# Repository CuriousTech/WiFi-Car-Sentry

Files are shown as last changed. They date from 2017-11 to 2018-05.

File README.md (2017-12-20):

# WiFi Car Sentry
Low power car monitor and control system  
  
Revision 2  
  
Using the ESP07, it connects with the home WiFi to report information on timer using DeepSleep.  Remember to remove the red LED on the ESP to reduce current.  This new revision uses a switching regulator for the lowest current possible.  It uses about 25mA on, and 39µA in sleep at 12.5V.  
  
I/O peripherals:  
  OLED (optional for temporary display)  
  DHT22 for temperature and Rh  
  0-17V analog voltage reading  
  2x 1-40V digital input (for sensing if something is on)  
  3x sink inputs (alarm or sensor)  
  3 sink outputs for controlling relays, etc (the bom has 7.6A MOSFETs)  
  Plus extra O/I for GPS or other sensors. The outputs can be used to switch them off for more power saving.  
  
esp07carsentry
esp07pmwin
esp07cs_wp

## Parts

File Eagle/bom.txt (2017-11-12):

ESP-07
OLED        0.96" I2C (GND on pin 1)
DHT-22
3V3 VR      LMR16006YQ3DDCRQ1
D5  SOT-223    NSVR0320MW2T1G
L1  0805 6.8uF IFSC0806AZER6R8M01
R1-R5,R7    10K 0805 (or 0603)
R6,R9,R14   1K
R8          2.2K
R10         100K
R11         6.34K
R12,R13      4.7K
C1  0805 2.2uF
C4  0805 10uF  08056C106KAT2A
C3,C6,C7,C8,C9,C11 0.1uF (0805 or 0603)
Q1,Q3,Q6    SOT-23 P-Channel FET <3V gate threshold (SI2369DS-T1-GE3)
Q2          SOT-23 N-Channel FET (PMV20ENR)
Q4,Q5       SOT-23 General purpose NPN

FLASH       4x2mm buttton
RX/TX/GND   3-pin 0.1" header (hold in place, then use OTA)

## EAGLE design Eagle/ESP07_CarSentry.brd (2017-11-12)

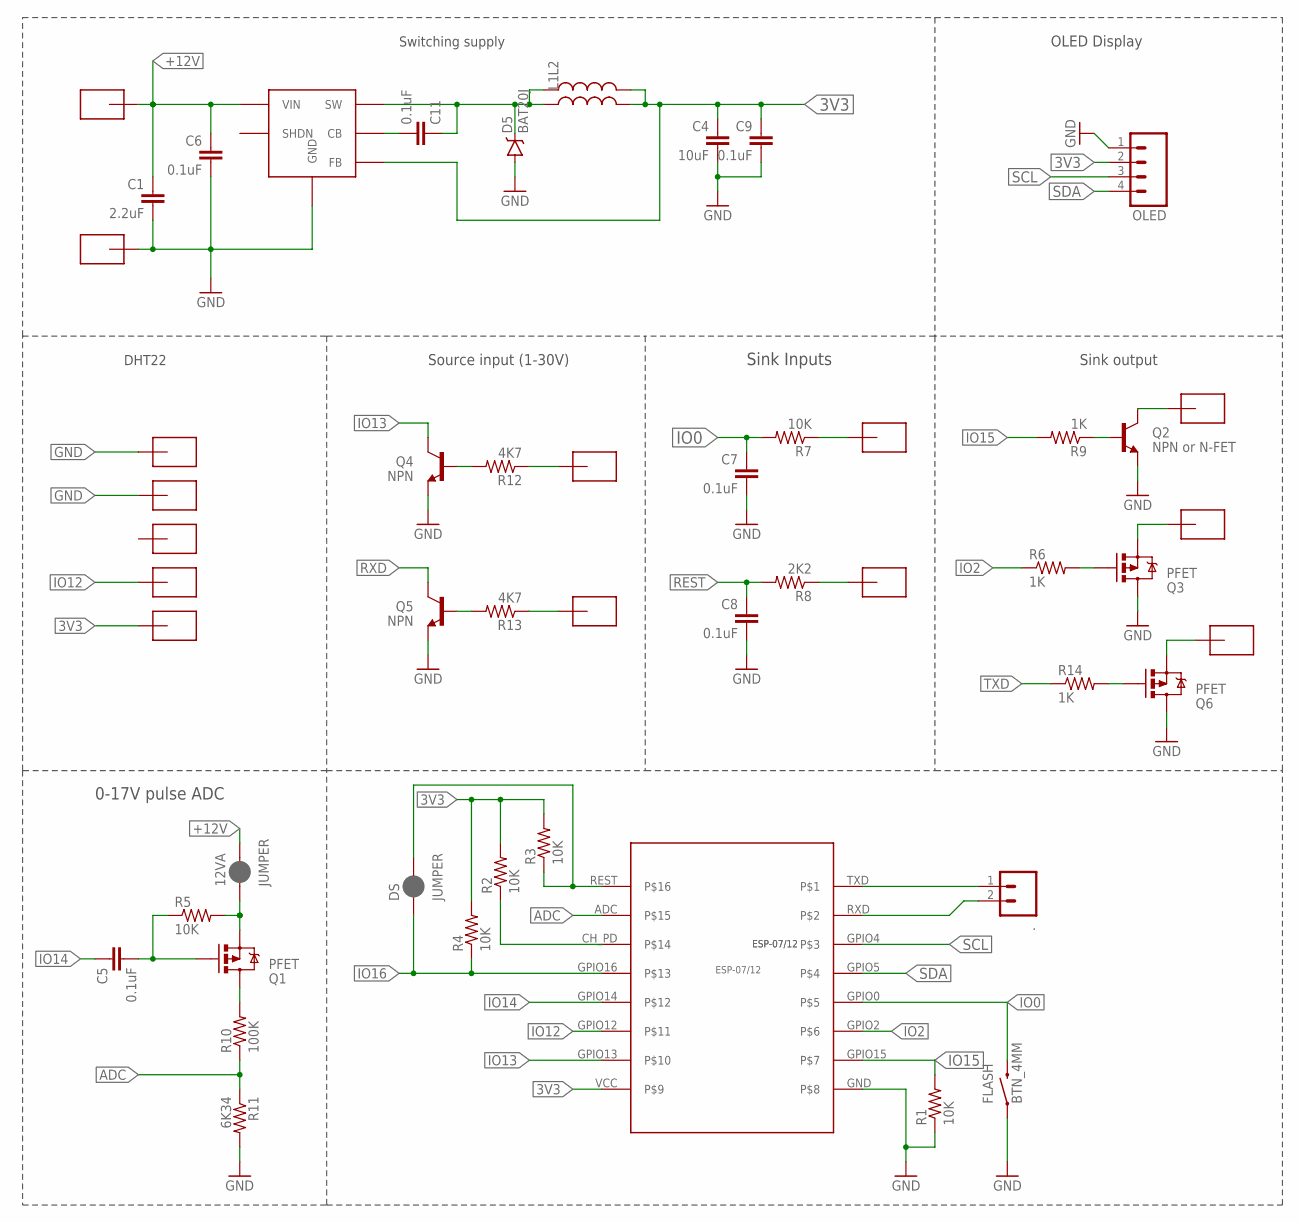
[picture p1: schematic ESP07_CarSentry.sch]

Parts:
12VA: JUMPER; PAD-JUMPER-2-NC_BY_PASTE_YES_SILK
.: M02PTH; 1X02
C1: 2.2uF; 0805-CAP
C4: 10uF; 0805-CAP
C5, C6, C7, C8, C9, C11: 0.1uF; 0805-CAP
D5: BAT20J; SOD-323
DS: JUMPER; PAD-JUMPER-2-NC_BY_PASTE_YES_SILK
FLASH: BTN_4MM
L1, L2: INDUCTOR0805; 0805
OLED: M04LOCK; 1X04_LOCK
Q1, Q3, Q6: PFET; SOT23-3
Q2: NPN or N-FET; SOT23-3
Q4, Q5: NPN; SOT23-3
R1, R2, R3, R4, R5, R7: 10K; 0805
R6, R9, R14: 1K; 0805
R8: 2K2; 0805
R10: 100K; 0805
R11: 6K34; 0805
R12, R13: 4K7; 0805
U$1: ESP-07/12
U$2, U$3, U$4, U$5, U$6, U$7, U$8, U$9, U$10, U$11, U$12, U$13, U$14, U$16: SMD-PAD1
VREG1: LMR16006YQ3DDCRQ1; SOT-23-6

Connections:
3V3: C4.1, C9.1, L1.2, L2.2, OLED.2, R2.2, R3.2, R4.2, U$1.VCC, U$4.>NAME, VREG1.3 (FB)
+12V: 12VA.2, C1.1, C6.1, U$16.>NAME, VREG1.5 (VIN)
ADC: R10.1, R11.1, U$1.ADC
ADCHI: 12VA.1, Q1.2 (S), R5.2
GND: C1.2, C4.2, C6.2, C7.2, C8.2, C9.2, D5.A, FLASH.1, OLED.1, Q2.2 (E), Q3.3 (D), Q4.2 (E), Q5.2 (E), Q6.3 (D), R1.1, R11.2, U$1.GND, U$6.>NAME, U$8.>NAME, U$11.>NAME, VREG1.2 (GND)
IO0: C7.1, FLASH.2, R7.2, U$1.GPIO0
IO2: R6.1, U$1.GPIO2
IO12: U$1.GPIO12, U$5.>NAME
IO13: Q4.3 (C), U$1.GPIO13
IO14: C5.1, U$1.GPIO14
IO15: R1.2, R9.2, U$1.GPIO15
IO16: DS.1, R4.1, U$1.GPIO16
unnamed: Q1.3 (D), R10.2
unnamed: Q3.1 (G), R6.2
unnamed: C5.2, Q1.1 (G), R5.1
unnamed: Q3.2 (S), U$9.>NAME
unnamed: R7.1, U$14.>NAME
unnamed: Q2.1 (B), R9.1
unnamed: Q2.3 (C), U$3.>NAME
unnamed: R8.1, U$12.>NAME
unnamed: Q4.1 (B), R12.2
unnamed: R12.1, U$2.>NAME
unnamed: R2.1, U$1.CH_PD
unnamed: Q5.1 (B), R13.2
unnamed: C11.1, D5.C, L1.1, L2.1, VREG1.6 (SW)
unnamed: C11.2, VREG1.1 (CB)
unnamed: R13.1, U$10.>NAME
unnamed: Q6.2 (S), U$13.>NAME
unnamed: Q6.1 (G), R14.2
REST: C8.1, DS.2, R3.1, R8.2, U$1.REST
RXD: ..2, Q5.3 (C), U$1.RXD
SCL: OLED.3, U$1.GPIO4
SDA: OLED.4, U$1.GPIO5
TXD: ..1, R14.1, U$1.TXD

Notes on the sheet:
0-17V pulse ADC
Sink Inputs
DHT22
Sink output
Source input (1-30V)
OLED Display
Switching supply

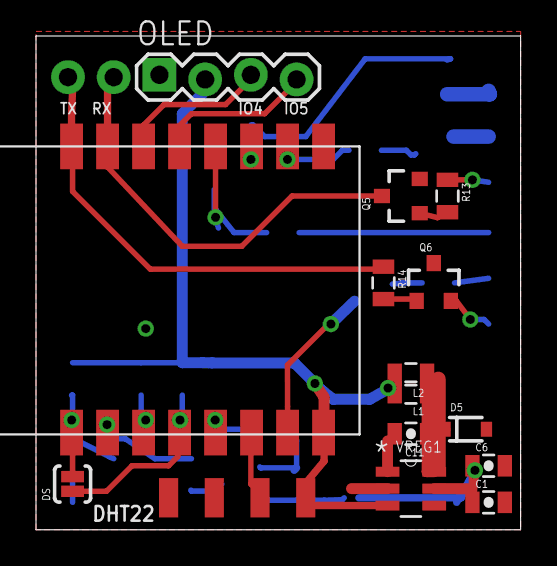
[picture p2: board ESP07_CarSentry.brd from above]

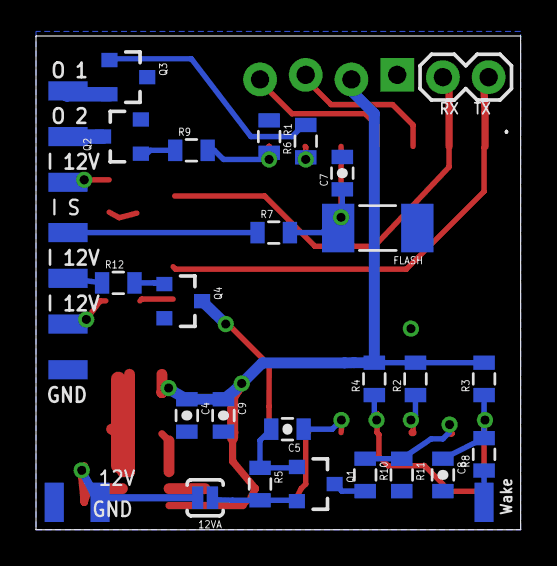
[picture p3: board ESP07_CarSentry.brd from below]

Board: 2 copper layers, 26.9 x 27.4 mm, 52 parts (34 on the bottom side), 34 nets.

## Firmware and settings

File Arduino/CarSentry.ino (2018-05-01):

/**The MIT License (MIT)

Copyright (c) 2017 by Greg Cunningham, CuriousTech

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
THE SOFTWARE IS PROVIDED "AS IS", WITHOUT WARRANTY OF ANY KIND, EXPRESS OR
IMPLIED, INCLUDING BUT NOT LIMITED TO THE WARRANTIES OF MERCHANTABILITY,
FITNESS FOR A PARTICULAR PURPOSE AND NONINFRINGEMENT. IN NO EVENT SHALL THE
AUTHORS OR COPYRIGHT HOLDERS BE LIABLE FOR ANY CLAIM, DAMAGES OR OTHER
LIABILITY, WHETHER IN AN ACTION OF CONTRACT, TORT OR OTHERWISE, ARISING FROM,
OUT OF OR IN CONNECTION WITH THE SOFTWARE OR THE USE OR OTHER DEALINGS IN THE
SOFTWARE.
*/

//uncomment to enable Arduino IDE Over The Air update code
#define OTA_ENABLE

//#define DEBUG
//#define USE_SPIFFS

#include <Wire.h>
#include <ssd1306_i2c.h> // https://github.com/CuriousTech/WiFi_Doorbell/tree/master/Libraries/ssd1306_i2c
#include <EEPROM.h>
#include <ESP8266mDNS.h>
#include "WiFiManager.h"
#include <ESPAsyncWebServer.h> // https://github.com/me-no-dev/ESPAsyncWebServer
#ifdef USE_SPIFFS
#include <FS.h>
#include <SPIFFSEditor.h>
#else
#include "pages.h"
#endif
#ifdef OTA_ENABLE
#include <FS.h>
#include <ArduinoOTA.h>
#endif
#include <OneWire.h>
#include <TimeLib.h> // http://www.pjrc.com/teensy/td_libs_Time.html
#include <UdpTime.h>
#include <DHT.h>  // http://www.github.com/markruys/arduino-DHT
#include "eeMem.h"
#include <JsonClient.h> // https://github.com/CuriousTech/ESP8266-HVAC/tree/master/Libraries/JsonParse

const char controlPassword[] = "password";    // device password for modifying any settings
const int serverPort = 81;                    // HTTP port

#define IN1       0  // Sink input 1 (Direct sink 5V tolerant)
#define OUT3      1  // TX Sink output 3 MOSFET (high to sink)
#define OUT1      2  // Sink output 1 MOSFET (low to sink) (Note: Rev 1 has P-channel here)
#define ESP_LED   2  // Blue LED on ESP07 (on low)
#define IN2       3  // RX 1~40V input (sink)
#define SDA       4  // OLED
#define SCL       5  // OLED
#define DHT22IO  12  // The DHT22
#define IN12V    13  // 1~30V input (sink) use PULLUP
#define VOLTFET  14  // voltage reading MOSFET
#define OUT2     15  // Sink output 2 MOSFET (high to sink)
#define SLEEP    16  // Wake pin

uint32_t lastIP;

SSD1306 display(0x3C, SDA, SCL); // Initialize the oled display for address 0x3C, SDA=4, SCL=5 (is the OLED mislabelled?)
int displayOnTimer;

eeMem eemem;
DHT dht;
UdpTime utime;

WiFiManager wifi;  // AP page:  192.168.4.1
AsyncWebServer server( serverPort );
AsyncEventSource events("/events"); // event source (Server-Sent events)
AsyncWebSocket ws("/ws"); // access at ws://[esp ip]/ws

uint16_t rh;
int16_t carTemp;
uint16_t volts;
uint16_t ssCnt = 10;
const char hostName[] = "CarSentry";
bool bKeyGood;
uint32_t sleepDelay = 10; // default value for WebSocket close -> sleepTimer
uint32_t sleepTimer = 60; // seconds delay after startup to enter sleep (Note: even if no AP found)
int8_t openCnt;
uint8_t nPulse;
uint8_t pulseCh;
IPAddress WSIP;

void jsonCallback(int16_t iEvent, uint16_t iName, int iValue, char *psValue);
JsonClient jsonParse(jsonCallback);
JsonClient jsonPush(jsonCallback);
void locCallback(int16_t iEvent, uint16_t iName, int iValue, char *psValue);
JsonClient locator(locCallback);

const char days[7][4] = {"Sun","Mon","Tue","Wed","Thr","Fri","Sat"};
const char months[12][4] = {"Jan","Feb","Mar","Apr","May","Jun","Jul","Aug","Sep","Oct","Nov","Dec"};

String dataJson()
{
  String s = "{";
  s += "\"t\": ";  s += now() - ((ee.tz + utime.getDST()) * 3600);
  s += ", \"ct\": ";  s += sDec(carTemp);
  s += ", \"rh\": ";   s += sDec(rh);
  s += ", \"v\": ";   s += (float)volts / 100;
  s += ", \"in1\": ";   s += digitalRead(IN1) ? 0:1;
  s += ", \"in2\": ";   s += digitalRead(IN2) ? 0:1;
  s += ", \"in12v\": ";   s += digitalRead(IN12V) ? 0:1;
  s += ", \"lat\": \"";   s += ee.szLat;
  s += "\", \"lon\": \"";   s += ee.szLon;
  s += "\"}";
  return s;
}

String setJson() // settings
{
  String s = "{";
  s += "\"o\":";    s += ee.bEnableOLED;
  s += ",\"tz\":";  s += ee.tz;
  s += ", \"gt\": ";   s += ee.get_time;
  s += ", \"gl\": ";   s += ee.get_loc;
  s += ",\"o1\":";  s += digitalRead(OUT1) ? 0:1;
  s += ",\"o2\":";  s += digitalRead(OUT2) ? 1:0;
  s += ",\"o3\":";  s += digitalRead(OUT3) ? 1:0;
  s += ",\"to\": "; s += ee.time_off;
  s += ", \"ro\": ";   s += ee.roaming;
  s += ",\"d\": \""; s += ee.szDomain;
  s += "\"}";
  return s;
}

void parseParams(AsyncWebServerRequest *request)
{
  static char temp[256];
  char password[64];
  int val;

 if(request->params() == 0)
    return;

  // get password first
  for ( uint8_t i = 0; i < request->params(); i++ ) {
    AsyncWebParameter* p = request->getParam(i);
    p->value().toCharArray(temp, 100);
    String s = wifi.urldecode(temp);
    switch( p->name().charAt(0)  )
    {
      case 'k': // key
        s.toCharArray(password, sizeof(password));
        break;
    }
  }

  uint32_t ip = request->client()->remoteIP();

  if(strcmp(controlPassword, password))
  {
    lastIP = ip;
    return;
  }

  lastIP = ip;

  for ( uint8_t i = 0; i < request->params(); i++ ) {
    AsyncWebParameter* p = request->getParam(i);
    p->value().toCharArray(temp, 100);
    String s = wifi.urldecode(temp);

    val = s.toInt();

    switch( p->name().charAt(0)  )
    {
      case 'h': // host IP / port  (call from host with ?h=80)
        ee.hostIP = ip;
        ee.hostPort = val ? val:80;
        break;
      case 't': // time off
        ee.time_off = val;
        break;
      case 's': // AP SSID
        s.toCharArray(ee.szSSID, sizeof(ee.szSSID));
        break;
      case 'p': // AP password
        wifi.setPass(s.c_str());
        break;
    }
  }
}

String sDec(int t) // just 123 to 12.3 string
{
  String s = String( t / 10 ) + ".";
  s += t % 10;
  return s;
}

// Time in hh:mm[:ss][AM/PM]
String timeFmt(bool do_sec, bool do_M)
{
  String r = "";
  if(hourFormat12() < 10) r = " ";
  r += hourFormat12();
  r += ":";
  if(minute() < 10) r += "0";
  r += minute();
  if(do_sec)
  {
    r += ":";
    if(second() < 10) r += "0";
    r += second();
    r += " ";
  }
  if(do_M)
  {
      r += isPM() ? "PM":"AM";
  }
  return r;
}

void handleS(AsyncWebServerRequest *request) { // standard params, but no page
  parseParams(request);

  String page = "{\"ip\": \"";
  page += WiFi.localIP().toString();
  page += ":";
  page += serverPort;
  page += "\"}";
  request->send ( 200, "text/json", page );
}

void onEvents(AsyncEventSourceClient *client)
{
  events.send(dataJson().c_str(), "state");
}

void sendState()
{
  String s = dataJson();
  events.send(s.c_str(), "state");
  ws.textAll(String("state;") + s);
  ssCnt = 58;
}

const char *jsonListCmd[] = { "cmd",
  "key",
  "oled",
  "TZ", // location
  "TO", // time_off
  "sleep",
  "O1", // OUT1
  "O2",
  "O3",
  "PLS", // Pulse OUTn for 1 second
  "GT", // get time
  "GL", // get location
  "HI", // host IP/port
  "SD", // set domain
  "RO", // roaming
  NULL
};
      
void jsonCallback(int16_t iEvent, uint16_t iName, int iValue, char *psValue)
{
  if(!bKeyGood && iName) return; // only allow for key

  switch(iEvent)
  {
    case 0: // cmd
      switch(iName)
      {
        case 0: // key
          if(!strcmp(psValue, controlPassword)) // first item must be key
            bKeyGood = true;
          break;
        case 1: // OLED
          ee.bEnableOLED = iValue ? true:false;
          break;
        case 2: // TZ
          ee.tz = iValue;
          utime.start();
          break;
        case 3: // TO
          ee.time_off = iValue;
          break;
        case 4: // sleep
          sleepDelay = constrain(iValue, 1, 10000);
          break;
        case 5: // O1=n
          digitalWrite(OUT1, iValue ? LOW:HIGH);
          break;
        case 6: // O2=n
          digitalWrite(OUT2, iValue ? HIGH:LOW);
          break;
        case 7: // O3=n
          digitalWrite(OUT3, iValue ? HIGH:LOW);
          break;
        case 8: // PLS=Ch
          nPulse = 2;
          pulseCh = iValue;
          break;
        case 9: // GT
          ee.get_time = iValue ? true:false;
          break;
        case 10: // GL
          ee.get_loc = iValue ? true:false;
          break;
        case 11: // host IP / port  (call from host with ?h=80)
          ee.hostIP = WSIP;
          ee.hostPort = iValue ? iValue:80;
          break;
        case 12: // global domain
          strncpy(ee.szDomain, psValue, sizeof(ee.szDomain));
          break;
        case 13: // RO
          ee.roaming = iValue ? true:false;
          break;
      }
      break;
  }
}

const char *jsonListLoc[] = { "data",
  "result",
  "lat",
  "lon",
  "time",
  NULL
};
      
void locCallback(int16_t iEvent, uint16_t iName, int iValue, char *psValue)
{
  switch(iEvent)
  {
    case 0: // cmd
      switch(iName)
      {
        case 0: // result
          break;
        case 1: // lat
          strncpy(ee.szLat, psValue, sizeof(ee.szLat) );
          ee.locRoam = wifi.isSecure();
          break;
        case 2: // lon
          strncpy(ee.szLon, psValue, sizeof(ee.szLon) );
          break;
        case 3: // time
          utime.set(iValue, ee.tz);
          break;
      }
      break;
  }
}

void onWsEvent(AsyncWebSocket * server, AsyncWebSocketClient * client, AwsEventType type, void * arg, uint8_t *data, size_t len)
{  //Handle WebSocket event
  String s;

  switch(type)
  {
    case WS_EVT_CONNECT:      //client connected
      s = String("state;") + dataJson().c_str();
      client->text(s);
      s = String("set;") + setJson().c_str();
      client->text(s);
      client->ping();
      WSIP = client->remoteIP();
      openCnt++;
      break;
    case WS_EVT_DISCONNECT:    //client disconnected
      if(openCnt)
        openCnt--;
      if(sleepDelay)
        sleepTimer = sleepDelay;
      break;
    case WS_EVT_ERROR:    //error was received from the other end
      break;
    case WS_EVT_PONG:    //pong message was received (in response to a ping request maybe)
      break;
    case WS_EVT_DATA:  //data packet
      AwsFrameInfo * info = (AwsFrameInfo*)arg;
      if(info->final && info->index == 0 && info->len == len){
        //the whole message is in a single frame and we got all of it's data
        if(info->opcode == WS_TEXT){
          data[len] = 0;

          char *pCmd = strtok((char *)data, ";"); // assume format is "name;{json:x}"
          char *pData = strtok(NULL, "");
          if(pCmd == NULL || pData == NULL) break;
          bKeyGood = false; // for callback (all commands need a key)
          jsonParse.process(pCmd, pData);
        }
      }
      break;
  }
}

volatile bool bIn1Triggered;

void in1ISR()
{
  bIn1Triggered = true;
}

volatile bool bIn12VTriggered;

void in12VISR()
{
  bIn12VTriggered = true;
}

void setup()
{
  pinMode(IN1, INPUT_PULLUP);
  pinMode(IN12V, INPUT_PULLUP);
  pinMode(VOLTFET, OUTPUT);
  digitalWrite(OUT1, HIGH);
  pinMode(OUT1, OUTPUT);
  pinMode(OUT2, OUTPUT);

  // initialize dispaly
  display.init();
  display.flipScreenVertically();

#ifdef DEBUG
  Serial.begin(115200);
  delay(3000);
  Serial.println();
#endif

  WiFi.hostname(hostName);
  if(!wifi.autoConnect(hostName, controlPassword, ee.roaming)) // Tries config AP.  goes to DeepSleep if not found
  {
    if(digitalRead(IN1) == LOW) // hold the flash button down a couple seconds after powerup to clear SSID and password
    {                           // don't use this if IN1 is connected to something
      ee.szSSID[0] = 0;
      ee.szSSIDPassword[0] = 0;
      eemem.update();
#ifdef DEBUG
      Serial.println("SSID cleared");
      delay(1000);
#endif
    }
    uint32_t us = 1000000; // 1 second to restart
    display.displayOff();
    ESP.deepSleep(us, WAKE_RF_DEFAULT);
  }

  if(wifi.isCfg() == false)
  {
#ifdef DEBUG
    Serial.println("");
    Serial.println("WiFi connected");
    Serial.print("IP address: ");
    Serial.println(WiFi.localIP());
#endif
    MDNS.begin ( hostName, WiFi.localIP() );
  }

  MDNS.addService("http", "tcp", serverPort);

#ifdef USE_SPIFFS
  SPIFFS.begin();
  server.addHandler(new SPIFFSEditor("admin", controlPassword));
#endif

  attachInterrupt(IN1, in1ISR, FALLING);
  attachInterrupt(IN12V, in12VISR, CHANGE);

  // attach AsyncEventSource
  events.onConnect(onEvents);
  server.addHandler(&events);
  // attach AsyncWebSocket
  ws.onEvent(onWsEvent);
  server.addHandler(&ws);

  server.on ( "/", HTTP_GET | HTTP_POST, [](AsyncWebServerRequest *request) // Main webpage interface
  {
    parseParams(request);
    if(wifi.isCfg())
      request->send( 200, "text/html", wifi.page() ); // WIFI config page
    else
    {
    #ifdef USE_SPIFFS
      request->send(SPIFFS, "/index.htm");
    #else
      request->send_P(200, "text/html", page1);
    #endif
    }
  });
  server.on ( "/s", HTTP_GET | HTTP_POST, handleS );
  server.on ( "/set", HTTP_GET, [](AsyncWebServerRequest *request){
    request->send( 200, "text/json", setJson() );
  });
  server.on ( "/json", HTTP_GET, [](AsyncWebServerRequest *request){
    request->send( 200, "text/json", dataJson() );
  });

  server.onNotFound([](AsyncWebServerRequest *request){
    request->send(404);
  });
  server.on("/heap", HTTP_GET, [](AsyncWebServerRequest *request){
    request->send(200, "text/plain", String(ESP.getFreeHeap()));
  });

  server.on("/scan", HTTP_GET, [](AsyncWebServerRequest *request){
    String json = "[";
    int n = WiFi.scanComplete();
    if(n == -2){
      WiFi.scanNetworks(true);
    } else if(n){
      for (int i = 0; i < n; ++i){
        if(i) json += ",";
        json += "{";
        json += "\"rssi\":"+String(WiFi.RSSI(i));
        json += ",\"ssid\":\""+WiFi.SSID(i)+"\"";
        json += ",\"bssid\":\""+WiFi.BSSIDstr(i)+"\"";
        json += ",\"channel\":"+String(WiFi.channel(i));
        json += ",\"secure\":"+String(WiFi.encryptionType(i));
        json += ",\"hidden\":"+String(WiFi.isHidden(i)?"true":"false");
        json += "}";
      }
      WiFi.scanDelete();
      if(WiFi.scanComplete() == -2){
        WiFi.scanNetworks(true);
      }
    }
    json += "]";
    request->send(200, "text/json", json);
    json = String();
  });

  server.onFileUpload([](AsyncWebServerRequest *request, String filename, size_t index, uint8_t *data, size_t len, bool final){
  });
  server.onRequestBody([](AsyncWebServerRequest *request, uint8_t *data, size_t len, size_t index, size_t total){
  });

  server.on("/favicon.ico", HTTP_GET, [](AsyncWebServerRequest *request){
    AsyncWebServerResponse *response = request->beginResponse_P(200, "image/x-icon", favicon, sizeof(favicon));
    response->addHeader("Content-Encoding", "gzip");
    request->send(response);
  });
  server.begin();

#ifdef OTA_ENABLE
  ArduinoOTA.begin();
  ArduinoOTA.onStart([]() {
    eemem.update();
  });
#endif

  dht.setup(DHT22IO, DHT::DHT22);
  jsonParse.addList(jsonListCmd);

  if(wifi.isCfg() == false) // connected to the net
  {
    if(ee.get_time)
      utime.start();
    String sUri = String("/car?lon=\"");
    sUri += ee.szLon;
    sUri += "\"&lat=\"";
    sUri += ee.szLat;
    sUri += "\"";
    IPAddress ip(ee.hostIP);
    String url;
    if(wifi.isSecure())
      url = ip.toString();
    else
      url = ee.szDomain;
    jsonPush.begin(url.c_str(), sUri.c_str(), ee.hostPort, false, false, NULL, NULL);
    jsonPush.addList(jsonListCmd);
    if(ee.szLat[0] == 0 || ee.get_loc || !wifi.isSecure() || ee.locRoam) // only needed first time and when roaming, or was roaming last
      updateLocation();
  }

  sleepTimer = 60;
  ssCnt = 10; // reset to 10 seconds
}

void loop()
{
  static uint8_t hour_save, min_save, sec_save;
  static bool bLastOn;

  MDNS.update();
#ifdef OTA_ENABLE
  ArduinoOTA.handle();
#endif

  if(!wifi.isCfg() && ee.get_time)
    utime.check(ee.tz);

  if(bIn1Triggered) // sink triggered
  {
    bIn1Triggered = false;
//    Serial.println("IN1 triggered");
    events.send("IN1 triggered", "alert");
  }

  if(bIn12VTriggered) // 12V in changed
  {
    bIn12VTriggered = false;
//    Serial.print("12V changed to ");
//    Serial.println( digitalRead(IN12V) );
    sendState();
  }

  if(sec_save != second()) // only do stuff once per second
  {
    sec_save = second();

    static uint8_t dht_cnt = 1;
    if(--dht_cnt == 0)
    {
      dht_cnt = 5;
      uint16_t r = (uint16_t)(dht.getHumidity() * 10);
      if(dht.getStatus() == DHT::ERROR_NONE)
      {
        rh = r;
        carTemp = (dht.toFahrenheit(dht.getTemperature()) * 10);
      }//else Serial.println("Temp error");
    }

    if(--ssCnt == 0) // periodic data update
    {
       sendState();
    }

    switch(nPulse)
    {
      case 1:
        switch(pulseCh)
        {
          case 1: digitalWrite(OUT1, HIGH); break;
          case 2: digitalWrite(OUT2, LOW); break;
          case 3: digitalWrite(OUT3, LOW); break;
        }
        nPulse = 0;
        break;
      case 2:
        switch(pulseCh)
        {
          case 1: digitalWrite(OUT1, LOW); break;
          case 2: digitalWrite(OUT2, HIGH); break;
          case 3: digitalWrite(OUT3, HIGH); break;
        }
        nPulse = 1;
        break;
    }

    if(min_save != minute()) // only do stuff once per minute
    {
      min_save = minute();
      if (hour_save != hour()) // update time daily (at 2AM for DST)
      {
        if( (hour_save = hour()) == 2)
        {
          utime.start();
        }
      }
    }
    if(displayOnTimer)
    {
      displayOnTimer --;
    }

    // 100K / 6.34K to 1V : 17V = 1.008V or 1024 (17/1024=1.66)
    digitalWrite(VOLTFET, LOW);
    uint16_t v = analogRead(0);
    volts = (v * 1.582);
    digitalWrite(VOLTFET, HIGH);
//    Serial.print("volts ");
//    Serial.print(v);
//    Serial.print(" ");
//    Serial.println(volts);

    if(sleepTimer && openCnt == 0 && wifi.isCfg() == false) // don't sleep until all ws connections are closed
    {
      if(--sleepTimer == 0)
      {
        if(ee.time_off)
        {
          eemem.update(); // Update EE if anything changed before entering sleep
          delay(100);

//        uint32_t us = ee.time_off * 1000000 * 60;  // minutes to us
          uint32_t us = ee.time_off * 60022000;  // minutes to us adjusted
          display.displayOff();
          ESP.deepSleep(us, WAKE_RF_DEFAULT);
        }
      }
    }
  }
  
  if(wifi.isCfg())
    return;

  // draw the screen here
  display.clear();

  if(ee.bEnableOLED || displayOnTimer) // draw only ON indicator if screen off
  {
    display.setFontScale2x2(false); // the small text

    String s;
  
    s = timeFmt(true, true); // the default scroller
    s += "  ";
    s += days[weekday()-1];
    s += " ";
    s += String(day());
    s += " ";
    s += months[month()-1];
    s += "  ";

    Scroller(s);

    display.drawString( 8, 22, "Temp");
    display.drawPropString(2, 33, String((float)carTemp / 10, 1) + "]" ); // <- that's a degree symbol
    display.drawString(2, 52, String((float)rh / 10, 1) + "%");
    display.drawString( 88, 22, "Volts");
    display.drawPropString(74, 33, String((float)volts / 100, 1) + "v" );
  }
  display.display();
}

// Text scroller optimized for very long lines
void Scroller(String s)
{
  static int16_t ind = 0;
  static char last = 0;
  static int16_t x = 0;

  if(last != s.charAt(0)) // reset if content changed
  {
    x = 0;
    ind = 0;
  }
  last = s.charAt(0);
  int len = s.length(); // get length before overlap added
  s += s.substring(0, 18); // add ~screen width overlap
  int w = display.propCharWidth(s.charAt(ind)); // measure first char
  if(w > 100) w = 10; // bug in function (0 returns 11637)
  String sPart = s.substring(ind, ind + 18);
  display.drawPropString(x, 0, sPart );

  if( --x <= -(w))
  {
    x = 0;
    if(++ind >= len) // reset at last char
      ind = 0;
  }
}

#define min(a,b) ((a)<(b)?(a):(b))

void updateLocation()
{
  int n = min(WiFi.scanNetworks(false,true), 5);
  if (n <= 0) return;

  String multiAPString = "";
  for(int i = 0; i < n; i++)
  {
    if(i > 0)
      multiAPString += ",";
     multiAPString += WiFi.BSSIDstr(i) + "," + WiFi.RSSI(i);
  }
  char multiAPs[multiAPString.length() + 1];
  multiAPString.toCharArray(multiAPs, multiAPString.length());
  multiAPString = "/wifi?v=1.1&search=";
  multiAPString += encodeBase64(multiAPs, multiAPString.length());
  locator.begin("api.mylnikov.org", multiAPString.c_str(), 80, false, false, NULL, NULL);
  locator.addList(jsonListLoc);
}

/*
 * Base64 code by Rene Nyfenegger:
 * http://www.adp-gmbh.ch/cpp/common/base64.html
 */
String base64_chars = "ABCDEFGHIJKLMNOPQRSTUVWXYZabcdefghijklmnopqrstuvwxyz0123456789+/";

String encodeBase64(char* bytes_to_encode, unsigned int in_len)
{
  String ret;
  int i = 0;
  int j = 0;
  unsigned char char_array_3[3];
  unsigned char char_array_4[4];

  while (in_len--) {
    char_array_3[i++] = *(bytes_to_encode++);
    if (i == 3) {
      char_array_4[0] = (char_array_3[0] & 0xfc) >> 2;
      char_array_4[1] = ((char_array_3[0] & 0x03) << 4) + ((char_array_3[1] & 0xf0) >> 4);
      char_array_4[2] = ((char_array_3[1] & 0x0f) << 2) + ((char_array_3[2] & 0xc0) >> 6);
      char_array_4[3] = char_array_3[2] & 0x3f;

      for(i = 0; (i <4) ; i++)
        ret += base64_chars[char_array_4[i]];
      i = 0;
    }
  }

  if (i)
  {
    for(j = i; j < 3; j++)
      char_array_3[j] = '\0';

    char_array_4[0] = (char_array_3[0] & 0xfc) >> 2;
    char_array_4[1] = ((char_array_3[0] & 0x03) << 4) + ((char_array_3[1] & 0xf0) >> 4);
    char_array_4[2] = ((char_array_3[1] & 0x0f) << 2) + ((char_array_3[2] & 0xc0) >> 6);
    char_array_4[3] = char_array_3[2] & 0x3f;

    for (j = 0; (j < i + 1); j++)
      ret += base64_chars[char_array_4[j]];

    while((i++ < 3))
      ret += '=';

  }
  return ret;
}

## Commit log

2017-01-18 Added SSID clear using flash button
2017-03-25 Switched Out 2 to PFET
    [ESP07_CarSentry.sch]
2017-11-12 rev 3
    [ESP07_CarSentry.sch]
2017-11-12 rev 2 or something
    [ESP07_CarSentry.brd]
2018-05-01 Removed printfs

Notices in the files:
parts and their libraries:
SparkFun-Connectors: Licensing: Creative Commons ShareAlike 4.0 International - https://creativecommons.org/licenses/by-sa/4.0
